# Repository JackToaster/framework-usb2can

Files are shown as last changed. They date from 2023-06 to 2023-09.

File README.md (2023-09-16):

# framework CAN Interface


USB to CAN device that fits in a Framework laptop expansion card.

## Hardware

The USB to CAN device is based on the _STM32G431_ microcontroller and _TCAN1042_ CAN transceiver.

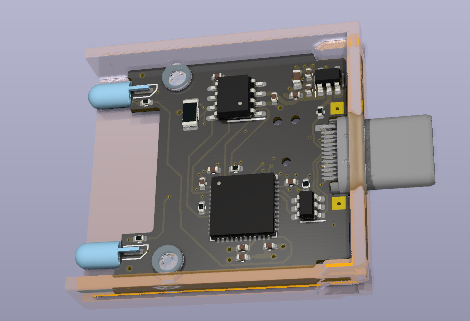
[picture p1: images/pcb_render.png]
Render of Framework USB to CAN PCB


The hardware is inspired by (but not a direct clone of) the [Canable 2.0](https://canable.io/).

It includes a removeable push-in spring connector for easy wiring to any CAN bus.

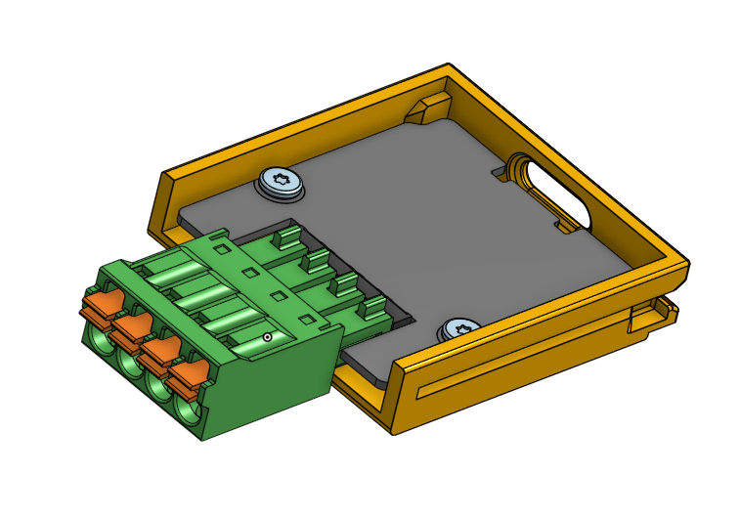
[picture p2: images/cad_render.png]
Render of expansion card with pluggable connector


## Software support

Supports CANFD (Up to 5Mbaud) with _slcan_ firmware, and socketcan on Linux with _candlelight_ firmware.

For software support, see the "_Software Support_" section at [canable.io](https://canable.io/)

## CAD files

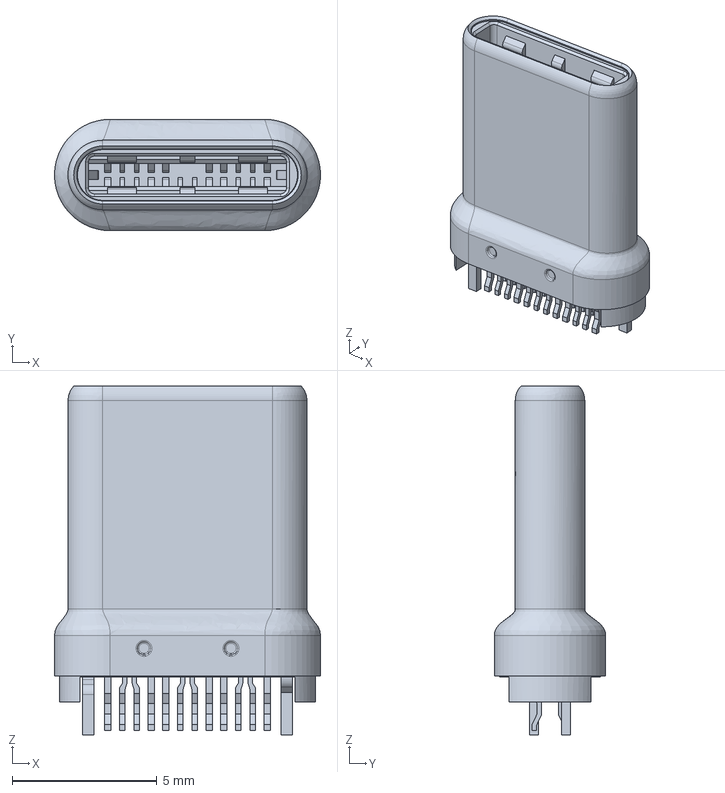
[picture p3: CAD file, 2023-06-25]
1054440001.stp
9.18 x 3.84 x 12.0 mm

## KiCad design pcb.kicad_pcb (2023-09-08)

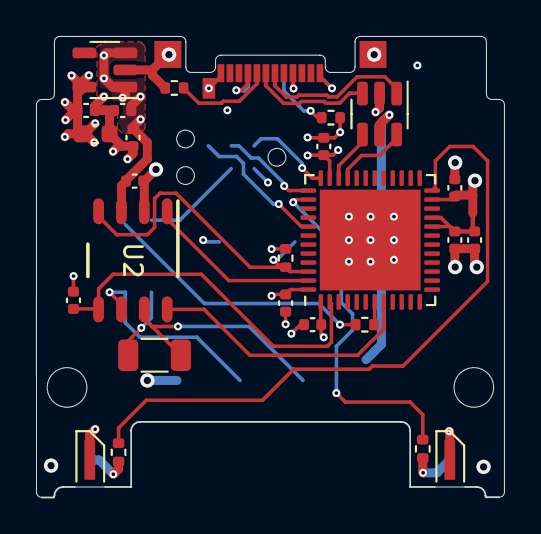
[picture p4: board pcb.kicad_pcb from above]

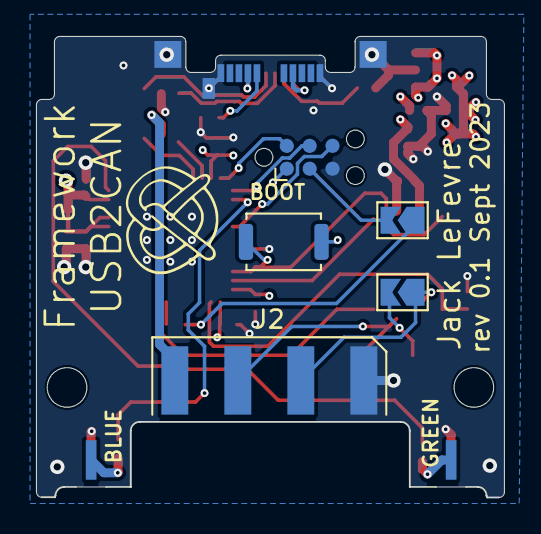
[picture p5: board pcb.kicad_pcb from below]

Board: 4 copper layers, 26.0 x 25.6 mm, 38 parts (7 on the bottom side), 27 nets.

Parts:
C1, C2, C4, C5, C6, C8, C10, C11: 100n; C_0402_1005Metric
C3: 4u7; C_0603_1608Metric
C9, C14, C15: 1u; C_0402_1005Metric
D2: Blue; LED_THT_Edge Mount
D3: Green; LED_THT_Edge Mount
H1, H2: MountingHole; MountingHole_2.2mm_M2
J1: TC2030-NL; Tag-Connect_TC2030-IDC-NL_2x03_P1.27mm_Vertical
J2: Conn_01x04; p3_5_edge_header
JP1: TERM; SolderJumper-2_P1.3mm_Open_TrianglePad1.0x1.5mm
JP2: RESET; SolderJumper-2_P1.3mm_Open_TrianglePad1.0x1.5mm
NT1: NetTie_2; NetTie-2_SMD_Pad0.5mm
P1: USB_C_Plug; USB_C_Plug_Molex_105444
R1, R2: 5.1k; R_0402_1005Metric
R3: 220k; R_0402_1005Metric
R4: 120; R_1206_3216Metric
R5, R9, R10: 330R; R_0402_1005Metric
SW1: BOOT; SW_Push_SPST_NO_Alps_SKRK
TP1, TP2, TP3, TP4: TestPoint; TestPoint_Pad_1.5x1.5mm
U1: WE-TVS-82400102; SOT-23-6
U2: TCAN1042HGVDQ1; D0008A_N
U3: STM32G431CBUx; QFN-48-1EP_7x7mm_P0.5mm_EP5.6x5.6mm
U9: AP2112K-3.3; SOT-23-5

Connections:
+3V3: C3.1, C4.1, C5.1, C6.1, C8.1, C15.1, J1.1 (VCC), NT1.1, SW1.1, U3.1 (VBAT), U3.23 (VDD), U3.35 (VDD), U3.48 (VDD), U9.5 (VOUT)
/SSD+: P1.A6 (D+), U1.3
/SSD-: P1.A7 (D-), U1.1
CANRX: R3.1, SW1.2, U2.4 (RXD), U3.46 (PB8)
CANTX: U2.1 (TXD), U3.47 (PB9)
CAN_IOPWR: C1.1, U2.5 (VIO), U3.2 (PC13)
CAN_STBY: U2.8 (STB), U3.8 (PA0)
GND: C1.2, C2.2, C3.2, C4.2, C5.2, C6.2, C8.2, C9.2, C10.2, C11.2, C14.2, C15.2, D2.1 (K), D3.1 (K), J1.5 (GND), J2.1, P1.A1 (GND), P1.A12 (GND), P1.B1 (GND), P1.B12 (GND), P1.S1 (SHIELD), R1.2, R2.2, R3.2, TP1.1, TP2.1, TP3.1, TP4.1, U1.2, U2.2 (GND), U3.49 (VSS), U9.2 (GND)
LEDB: R9.1, U3.38 (PA15)
LEDG: R10.1, U3.24 (PB11)
unnamed: D2.2 (A), R9.2
unnamed: D3.2 (A), R10.2
unnamed: J2.2, JP1.1 (A), U2.6 (CANL)
unnamed: J2.3, R4.1, U2.7 (CANH)
unnamed: JP1.2 (B), R4.2
unnamed: JP2.1 (A), R5.1
unnamed: P1.A5 (CC), R1.1
unnamed: P1.B5 (VCONN), R2.1
unnamed: R5.2, U3.7 (PG10)
SWCLK: J1.4 (SWCLK), U3.37 (PA14)
SWDIO: J1.2 (SWDIO), U3.36 (PA13)
SWO: J1.6 (SWO), U3.41 (PB3)
USB_D+: U1.4, U3.34 (PA12)
USB_D-: U1.6, U3.33 (PA11)
VBUS: C2.1, C11.1, C14.1, J2.4, P1.A4 (VBUS), P1.A9 (VBUS), P1.B4 (VBUS), P1.B9 (VBUS), U1.5, U2.3 (VCC), U9.1 (VIN), U9.3 (EN)
VDDA: C9.1, C10.1, NT1.2, U3.20 (VREF+), U3.21 (VDDA)
nRESET: J1.3 (~RESET), JP2.2 (B)

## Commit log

2023-06-20 schematic done
    [pcb.kicad_pcb, pcb.kicad_sch]
2023-06-25 Layout and routing
    [1054440001.stp, pcb.kicad_pcb, pcb.kicad_sch]
2023-06-25 part numbers
    [pcb.kicad_pcb, pcb.kicad_sch]
2023-06-25 move parts around
    [pcb.kicad_pcb]
2023-06-25 update part numbers
    [pcb.kicad_sch]
2023-09-08 made usb2can schematic/pcb
    [pcb.kicad_pcb, pcb.kicad_sch]
2023-09-08 fixed erc
    [pcb.kicad_sch]
2023-09-08 clean up tracks/vias
    [pcb.kicad_pcb]
